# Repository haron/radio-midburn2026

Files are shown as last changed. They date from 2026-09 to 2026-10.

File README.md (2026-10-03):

# Радио

Радио с двумя ручками: одна выбирает город, другая эпоху, переключение идёт
через шум. Станции «в эфире»: вернёшься — песня ушла вперёд.

Модель корпуса: `Radio.stl`. Исходник:
<https://cad.onshape.com/documents/3f97c19d22cdfbb1ff89ef73/w/63b62facf99d46d81c1500a9/e/cb74c49569cd1aa5f598bcb6>

## Города

Лондон, Париж, Берлин, Рим, Краков, Москва, Нью-Йорк, Лос-Анджелес, Токио,
Тель-Авив, Буэнос-Айрес, Гавана, Дели

## Скачать музыку

[Поставь uv](https://docs.astral.sh/uv/getting-started/installation/), затем:

``` sh
uvx --with curl_cffi yt-dlp --cookies-from-browser chrome --js-runtimes node --remote-components ejs:github --no-warnings https://youtu.be/-bWo0ky8xAs
```

`chrome` замени на свой браузер.

## Установка

``` sh
brew install mpd ffmpeg mp3gain uv # Mac
sudo apt install mpd ffmpeg && curl -LsSf https://astral.sh/uv/install.sh | sh # Raspberry Pi
sudo systemctl disable --now mpd mpd.socket # Pi: штатный mpd держит звуковую карту
cp .env.example .env
```

## WiFi

`cp wifi.yaml.example wifi.yaml`, впиши сети, `make provision`. Уже настроенные
на Pi сети остаются, сети с тем же SSID обновляются. `wifi.yaml` не коммитится и
не копируется в `/opt/radio`.

## Музыка

``` text
music/
  01_Paris/
    1_30s/*.mp3
    2_60s/*.mp3
    3_90s/*.mp3
  02_London/
    ...
static.mp3
```

- Порядок — по имени папки, ставь числовые префиксы.
- Ручка эпох идёт по всем эпохам всех городов; где эпохи нет — шум. Папки без
  MP3 игнорируются.
- Из `static.mp3` собирается петля `static.flac`; для нового клипа поправь точки
  обрезки в `Makefile`.
- `make normalize` выравнивает громкость (нужен `mp3gain`).

## Запуск

``` sh
make local
```

- Клавиатура: ←/→ или A/D — город, ↑/↓ или W/S — эпоха, T — случайное блуждание.
  На краях ручки упираются.
- На Pi — энкодеры KY-040: CLK/DT на BCM-пины из `.env`, `+` на 3.3V, GND на
  GND.
- Код и конфиг одни для Mac и Pi, аудиовыход определяется сам.
- mpd живёт после выхода и перезапускается при старте. Остановить:
  `pkill -f radio-mpd.conf`.

## Подсветка шкалы

Адресная лента на ESP32 с WLED, подключена к Pi (или Mac) по USB, без WiFi.

- WLED: Config → Sync Interfaces → Serial baud `115200`; LED Preferences → тип
  `WS281x` (RGB, не RGBW, иначе светодиоды съезжают), длина покрывает
  максимальный индекс из `.env`, ограничитель яркости 500 mA (питание от USB
  Pi), «Turn LEDs on after power up» выкл., boot preset `0`; WiFi Setup → AP
  opens `Never`, чтобы не светить точкой доступа.
- Порт: `ls /dev/cu.*` (Mac) или `ls /dev/serial/by-id/` (Pi) → `WLED_PORT`.
  Путь by-id переживает переподключение.
- Pi нужен блок 5.1V 2.5A: при просадке
  (`cat /sys/class/hwmon/hwmon1/in0_lcrit_alarm` = `1`) ESP32 циклически
  перезагружается и порт пропадает.
- На Pi пользователь должен быть в группе `dialout`:
  `sudo usermod -aG dialout $USER` и перелогиниться. Без порта, прав или ответа
  WLED радио не стартует.

## Охлаждение

Вентилятор 5V, 2 провода (30 или 40 мм) на GPIO Pi: красный на пин 4 (5V),
чёрный на пин 6 (GND), крутится всегда. Ставь на стенку корпуса, чтобы дул на
радиатор, с выходными дырками напротив; вход закрой сеткой от пыли.

`make healthcheck` — температура, троттлинг и просадки, сейчас и с загрузки.

## Шкала

`make radio.pdf` — шкала для печати (60×20 см + 3 мм под обрез) из `scale.py`;
`make radio.png` — превью. Собирать на Mac: нужен Helvetica Neue.

## Настройки (`.env`)

| Ключ | Что это |
|:---|:---|
| `PREVENT_SLEEP` | `1` — не давать машине уснуть |
| `LOG_LEVEL` | `INFO`, или `DEBUG` — ещё и все команды MPD |
| `WALK_IDLE` | секунд бездействия до случайного блуждания: станция 10–20 с, шум 2–7 с, пока не тронут ручку или клавишу |
| `STATIC_FADE` | секунд кроссфейда между музыкой и шумом |
| `STATIC_HOLD` | секунд чистого шума после поворота, \> 0; станция включается через `STATIC_FADE + STATIC_HOLD` |
| `ENC_LOC_A/B`, `ENC_EPOCH_A/B` | пины CLK/DT энкодеров (только Pi) |
| `WLED_PORT` | серийный порт WLED, пусто — без подсветки |
| `LED_LOCATIONS`, `LED_EPOCHS` | первый светодиод каждого диапазона, по одному на город и эпоху, напр. `0,5,10` |
| `LED_LOCATIONS_LEN`, `LED_EPOCHS_LEN` | светодиодов на город / эпоху |
| `LED_ON`, `LED_OFF` | цвета `RRGGBB` выбранной позиции и остальных |

## Логи

- В терминал.
- Syslog по UDP 514 широковещательно в локальную сеть. На сервере скопируй
  `rsyslog-radio.conf` в `/etc/rsyslog.d/` и перезапусти rsyslog; логи в
  `/var/log/radio.log`.
- Лог mpd: `/tmp/radio-mpd.log`.

Решения по дизайну: `AGENTS.md`.

## Песни

`songs.json`: город → эпоха (`1_early`, `2_middle`, `3_modern`) → 3–7 песен.
`make download` докачивает недостающие в `music/` (первый результат поиска
YouTube, нужен ffmpeg) и удаляет те, которых больше нет в списке.

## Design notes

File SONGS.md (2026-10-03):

# Songs

## London

- Early
  - John McCormack — It’s a Long Way to Tipperary (1914)
  - Vera Lynn — We’ll Meet Again (1939)
  - Vera Lynn — The White Cliffs of Dover (1942)
  - Lonnie Donegan — Rock Island Line (1955)
  - Cliff Richard — Move It (1958)
  - Monty Norman — James Bond Theme (1962)
- Middle
  - The Rolling Stones — (I Can’t Get No) Satisfaction (1965)
  - The Kinks — Waterloo Sunset (1967)
  - The Beatles — Hey Jude (1968)
  - David Bowie — Space Oddity (1969)
  - Queen — Bohemian Rhapsody (1975)
  - Sex Pistols — God Save the Queen (1977)
  - The Clash — London Calling (1979)
- Modern
  - Blur — Parklife (1994)
  - Oasis — Wonderwall (1995)
  - The Prodigy — Firestarter (1996)
  - Radiohead — Karma Police (1997)
  - Massive Attack — Teardrop (1998)
  - Arctic Monkeys — I Bet You Look Good on the Dancefloor (2005)
  - Amy Winehouse — Rehab (2006)

## Paris

- Early
  - Lucienne Boyer — Parlez-moi d’amour (1930)
  - Joséphine Baker — J’ai deux amours (1930)
  - Charles Trenet — La Mer (1946)
  - Édith Piaf — La Vie en rose (1947)
  - Yves Montand — Les feuilles mortes (1949)
- Middle
  - Jacques Brel — Ne me quitte pas (1959)
  - Édith Piaf — Non, je ne regrette rien (1960)
  - Charles Aznavour — La Bohème (1965)
  - Francis Lai — Un homme et une femme (1966)
  - Serge Gainsbourg & Jane Birkin — Je t’aime… moi non plus (1969)
  - Joe Dassin — Les Champs-Élysées (1969)
  - Dalida & Alain Delon — Paroles, paroles (1973)
- Modern
  - MC Solaar — Bouge de là (1991)
  - IAM — Je danse le Mia (1993)
  - Daft Punk — Around the World (1997)
  - Air — Sexy Boy (1998)
  - Manu Chao — Me gustas tú (2001)
  - Yann Tiersen — Comptine d’un autre été, l’après-midi (2001)
  - Christine and the Queens — Christine (2014)

## Berlin

- Early
  - Kurt Gerron — Die Moritat von Mackie Messer (1928)
  - Marlene Dietrich — Ich bin von Kopf bis Fuß auf Liebe eingestellt (1930)
  - Comedian Harmonists — Mein kleiner grüner Kaktus (1934)
  - Marlene Dietrich — Lili Marleen (1944)
  - Bully Buhlan — Ich hab noch einen Koffer in Berlin (1951)
- Middle
  - Drafi Deutscher — Marmor, Stein und Eisen bricht (1965)
  - Hildegard Knef — Für mich soll’s rote Rosen regnen (1968)
  - Kraftwerk — Das Model (1978)
  - Klaus Doldinger — Das Boot (1981)
  - Trio — Da Da Da (1982)
  - Nena — 99 Luftballons (1983)
  - Scorpions — Wind of Change (1990)
- Modern
  - Die Ärzte — Schrei nach Liebe (1993)
  - Paul van Dyk — For an Angel (1994)
  - Rammstein — Du hast (1997)
  - Seeed — Dickes B (2001)
  - Wir sind Helden — Guten Tag (2003)
  - Peter Fox — Schwarz zu blau (2008)
  - Paul Kalkbrenner — Sky and Sand (2008)

## Rome

- Early
  - Enrico Caruso — ’O sole mio (1916)
  - Beniamino Gigli — Mamma (1940)
  - Renato Carosone — Tu vuò fà l’americano (1956)
  - Domenico Modugno — Nel blu dipinto di blu (1958)
- Middle
  - Mina — Il cielo in una stanza (1960)
  - Ennio Morricone — Il buono, il brutto, il cattivo (1966)
  - Adriano Celentano — Azzurro (1968)
  - Lucio Battisti — Emozioni (1970)
  - Nino Rota — Speak Softly Love (The Godfather Love Theme) (1972)
  - Toto Cutugno — L’italiano (1983)
  - Lucio Dalla — Caruso (1986)
- Modern
  - 883 — Hanno ucciso l’Uomo Ragno (1992)
  - Jovanotti — L’ombelico del mondo (1995)
  - Eiffel 65 — Blue (Da Ba Dee) (1998)
  - Caparezza — Fuori dal tunnel (2003)
  - Francesco Gabbani — Occidentali’s Karma (2017)
  - Mahmood — Soldi (2019)
  - Måneskin — Zitti e buoni (2021)

## Moscow

- Early
  - Fyodor Chaliapin — Ey, ukhnem (1902)
  - Tamara Tsereteli — Dorogoy dlinnoyu (1925)
  - Leonid Utesov — Bublichki (1930)
  - Lidiya Ruslanova — Katyusha (1938)
  - Alexandrov Ensemble — Svyashchennaya voyna (1941)
  - Mark Bernes — Tyomnaya noch (1943)
  - Иван Шмелёв — Вот солдаты идут (1946)
  - Alexandrov Ensemble — Kalinka (1946)
- Middle
  - Vladimir Troshin — Podmoskovnye vechera (1956)
  - Aida Vedishcheva — Pesenka o medvedyakh (1967)
  - Vladimir Vysotsky — Pesnya o druge (1967)
  - Muslim Magomaev — Luch solntsa zolotogo (1973)
  - Alla Pugacheva — Million alykh roz (1982)
  - Alyans — Na zare (1987)
  - Kino — Gruppa krovi (1988)
- Modern
  - Kino — Kukushka (1990)
  - DDT — Chto takoe osen (1991)
  - Agata Kristi — Kak na voyne (1993)
  - Mumiy Troll — Utekay (1997)
  - Bi-2 — Polkovniku nikto ne pishet (2000)
  - Zemfira — Iskala (2000)
  - Splean — Vykhoda net (2001)

## New York

- Early
  - Benny Goodman — Sing, Sing, Sing (1937)
  - The Andrews Sisters — Bei Mir Bist Du Schön (1937)
  - Louis Armstrong — When the Saints Go Marching In (1938)
  - Billie Holiday — Strange Fruit (1939)
  - Glenn Miller — In the Mood (1939)
  - Duke Ellington — Take the ‘A’ Train (1941)
- Middle
  - Louis Armstrong — Go Down Moses (Let My People Go) (1958)
  - Ray Charles — Hit the Road Jack (1961)
  - Frank Sinatra — Fly Me to the Moon (1964)
  - Aretha Franklin — Respect (1967)
  - Ramones — Blitzkrieg Bop (1976)
  - Blondie — Heart of Glass (1979)
  - Grandmaster Flash and the Furious Five — The Message (1982)
- Modern
  - Run-DMC & Aerosmith — Walk This Way (1986)
  - Beastie Boys — (You Gotta) Fight for Your Right (To Party!) (1986)
  - Madonna — Vogue (1990)
  - Fugees — Killing Me Softly (1996)
  - The Strokes — Last Nite (2001)
  - 50 Cent — In da Club (2003)
  - Jay-Z & Alicia Keys — Empire State of Mind (2009)

## Los Angeles

- Early
  - Judy Garland — Over the Rainbow (1939)
  - Bing Crosby — White Christmas (1942)
  - Woody Guthrie — This Land Is Your Land (1944)
  - Hank Williams — Your Cheatin’ Heart (1953)
  - Bill Haley & His Comets — Rock Around the Clock (1954)
- Middle
  - Elvis Presley — Hound Dog (1956)
  - Chuck Berry — Johnny B. Goode (1958)
  - Henry Mancini — The Pink Panther Theme (1963)
  - The Beach Boys — Good Vibrations (1966)
  - The Doors — Light My Fire (1967)
  - The Doors — People Are Strange (1967)
  - Eagles — Hotel California (1976)
  - Michael Jackson — Billie Jean (1983)
- Modern
  - Nirvana — Smells Like Teen Spirit (1991)
  - Rage Against the Machine — Killing in the Name (1992)
  - Dr. Dre — Nuthin’ but a ‘G’ Thang (1992)
  - 2Pac — California Love (1995)
  - Red Hot Chili Peppers — Californication (1999)
  - Linkin Park — In the End (2001)
  - Kendrick Lamar — HUMBLE. (2017)

## Tokyo

- Early
  - Koto — Sakura Sakura (1950)
  - Hibari Misora — Ringo Oiwake (1952)
  - Akira Ifukube — Godzilla Main Theme (1954)
  - Kyu Sakamoto — Ue o Muite Aruko (1961)
- Middle
  - Sayuri Ishikawa — Tsugaru Kaikyo Fuyugeshiki (1977)
  - Yellow Magic Orchestra — Rydeen (1980)
  - Ryuichi Sakamoto — Merry Christmas Mr. Lawrence (1983)
  - Saburo Kitajima — Matsuri (1984)
  - Mariya Takeuchi — Plastic Love (1984)
  - Azumi Inoue — Tonari no Totoro (1988)
  - Hibari Misora — Kawa no Nagare no Yo ni (1989)
- Modern
  - Yoko Takahashi — Zankoku na Tenshi no Teze (1995)
  - Youmi Kimura — Itsumo Nando Demo (2001)
  - Yoshida Brothers — Rising (2003)
  - Perfume — Polyrhythm (2007)
  - Kyary Pamyu Pamyu — PonPonPon (2011)
  - Babymetal — Gimme Chocolate!! (2014)
  - Kenshi Yonezu — Lemon (2018)

## Tel Aviv

- Early
  - Yaffa Yarkoni — Hayu Leilot (1948)
  - Shoshana Damari — Kalaniyot (1951)
  - HaDudaim — Erev Shel Shoshanim (1957)
  - Ran & Nama — Hava Nagila (1959)
- Middle
  - Shuli Natan — Yerushalayim Shel Zahav (1967)
  - Lehakat HaNahal — Shir LaShalom (1969)
  - Arik Einstein — Ani ve’Ata (1971)
  - Kaveret — Yo Ya (1974)
  - Gali Atari & Milk and Honey — Hallelujah (1979)
  - Zohar Argov — HaPerach BeGani (1982)
  - Ofra Haza — Im Nin’alu (1984)
- Modern
  - Aviv Geffen — Achshav Meunan (1993)
  - Berry Sakharof — Bo (1996)
  - Hadag Nahash — Shirat HaSticker (2004)
  - Idan Raichel Project — Mima’amakim (2005)
  - Infected Mushroom — Becoming Insane (2007)
  - Omer Adam — Tel Aviv (2014)
  - Netta — Toy (2018)

## Buenos Aires

- Early
  - Carlos Gardel — Por una cabeza (1935)
  - Carlos Gardel — Volver (1935)
  - Atahualpa Yupanqui — Los ejes de mi carreta (1944)
  - Aníbal Troilo — Sur (1948)
  - Juan D’Arienzo — La Cumparsita (1951)
- Middle
  - Astor Piazzolla — Adiós Nonino (1959)
  - Los Gatos — La balsa (1967)
  - Mercedes Sosa — Alfonsina y el mar (1969)
  - Sui Generis — Canción para mi muerte (1972)
  - Astor Piazzolla — Libertango (1974)
  - Soda Stereo — Persiana americana (1986)
- Modern
  - Soda Stereo — De música ligera (1990)
  - Los Fabulosos Cadillacs — Matador (1993)
  - Bersuit Vergarabat — Se viene (2000)
  - Gotan Project — Santa María (del Buen Ayre) (2001)
  - Bajofondo — Pa’ bailar (2007)
  - Bizarrap & Nathy Peluso — Bzrp Music Sessions, Vol. 36 (2020)

## Havana

- Early
  - Don Azpiazu — El manisero (1930)
  - Joseíto Fernández — Guantanamera (1940)
  - Pérez Prado — Mambo No. 5 (1949)
  - Celia Cruz & La Sonora Matancera — Burundanga (1953)
  - Benny Moré — Bonito y sabroso (1953)
  - Orquesta Aragón — El bodeguero (1955)
- Middle
  - Carlos Puebla — Hasta siempre, Comandante (1965)
  - Pablo Milanés — Yolanda (1970)
  - Silvio Rodríguez — Ojalá (1978)
  - Los Van Van — Sandunguera (1982)
- Modern
  - Buena Vista Social Club — Chan Chan (1997)
  - Ibrahim Ferrer — Dos gardenias (1997)
  - Orishas — 537 C.U.B.A. (2000)
  - Gente de Zona & Marc Anthony — La Gozadera (2015)
  - Cimafunk — Me voy (2017)

## Delhi

- Early
  - K.L. Saigal — Jab Dil Hi Toot Gaya (1946)
  - Lata Mangeshkar — Aayega Aanewala (1949)
  - Geeta Dutt — Babuji Dheere Chalna (1954)
  - Mukesh — Mera Joota Hai Japani (1955)
  - Mohammed Rafi — Chaudhvin Ka Chand (1960)
  - Lata Mangeshkar — Pyar Kiya To Darna Kya (1960)
- Middle
  - Lata Mangeshkar — Ae Mere Watan Ke Logon (1963)
  - Kishore Kumar — Mere Sapno Ki Rani (1969)
  - Asha Bhosle — Dum Maro Dum (1971)
  - Kishore Kumar & Manna Dey — Yeh Dosti (1975)
  - R.D. Burman — Mehbooba Mehbooba (1975)
  - Vijay Benedict — I Am a Disco Dancer (1982)
- Modern
  - Sukhwinder Singh & Sapna Awasthi — Chaiyya Chaiyya (1998)
  - Daler Mehndi — Tunak Tunak Tun (1998)
  - Panjabi MC — Mundian To Bach Ke (1998)
  - A.R. Rahman — Jai Ho (2008)
  - Mohit Chauhan — Masakali (2009)
  - Aditi Paul & Osman Mir — Nagada Sang Dhol (2013)
  - Rahul Sipligunj & Kaala Bhairava — Naatu Naatu (2022)

## Kraków

- Early
  - Hanka Ordonówna — Miłość ci wszystko wybaczy (1933)
  - Mieczysław Fogg — Ostatnia niedziela (1936)
  - Molly Picon — Yidl Mitn Fidl (1936)
  - Eugeniusz Bodo — Umówiłem się z nią na dziewiątą (1937)
- Middle
  - Ewa Demarczyk — Karuzela z madonnami (1962)
  - Czesław Niemen — Dziwny jest ten świat (1967)
  - Krzysztof Komeda — Rosemary’s Baby (Lullaby) (1968)
  - Marek Grechuta & Anawa — Niepewność (1969)
  - Perfect — Autobiografia (1981)
  - Lady Pank — Mniej niż zero (1983)
  - Maanam — Kocham cię, kochanie moje (1984)
- Modern
  - Hey — Teksański (1993)
  - Kazik — 12 groszy (1997)
  - Myslovitz — Długość dźwięku samotności (1999)
  - Paktofonika — Jestem Bogiem (2000)
  - Brodka — Granda (2010)
  - Taco Hemingway — Deszcz na betonie (2016)
  - Dawid Podsiadło — Małomiasteczkowy (2018)

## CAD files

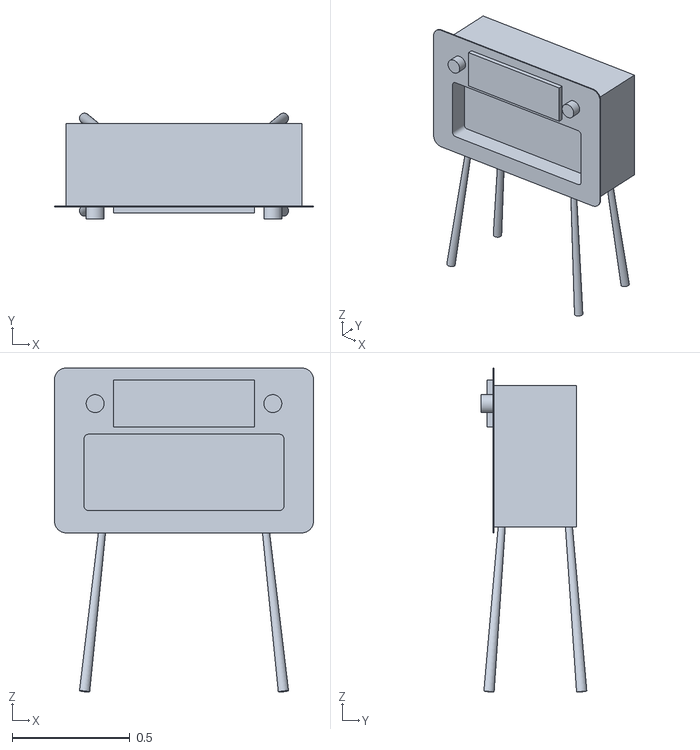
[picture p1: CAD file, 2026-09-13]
Radio.stl
1.10 x 0.449 x 1.38

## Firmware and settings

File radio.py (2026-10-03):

"""Two-knob radio: location × epoch stations, switched through static. Design notes in AGENTS.md."""
import atexit
import grp
import json
import logging
import logging.handlers
import os
import random
import re
import socket
import subprocess
import sys
import termios
import threading
import time
import tty
import zlib
from dataclasses import dataclass
from pathlib import Path

import psutil
import serial
from dotenv import load_dotenv
from mpd import MPDClient
from mutagen.mp3 import MP3

ROOT = Path(__file__).resolve().parent
MUSIC, STATIC = ROOT / "music", ROOT / "static.flac"  # seamless loop built by `make static.flac`
SOCK, CONF = "/tmp/radio-mpd.sock", Path("/tmp/radio-mpd.conf")
TICK = 0.02
WALK_PLAY, WALK_STATIC = (10, 20), (2, 7)  # random walk: seconds on a station, then of static
FLICKER, FLICKER_MIN = 0.06, 0.15  # selected LEDs during static: seconds per frame, lowest brightness
PI_MODEL = Path("/proc/device-tree/model")
ON_PI = PI_MODEL.exists() and "Raspberry Pi" in PI_MODEL.read_text()
KEYS = {"\x1b[D": ("location", -1), "a": ("location", -1), "\x1b[C": ("location", 1), "d": ("location", 1),
        "\x1b[A": ("epoch", 1), "w": ("epoch", 1), "\x1b[B": ("epoch", -1), "s": ("epoch", -1)}

log = logging.getLogger("radio")


class BroadcastSyslog(logging.handlers.SysLogHandler):
    """Syslog to each interface's broadcast address (macOS rejects 255.255.255.255); re-read per record."""

    def __init__(self):
        super().__init__(("255.255.255.255", 514))
        self.socket.setsockopt(socket.SOL_SOCKET, socket.SO_BROADCAST, 1)
        self.ident = "radio: "

    def emit(self, record):
        for addrs in psutil.net_if_addrs().values():
            for a in addrs:
                if a.family == socket.AF_INET and a.broadcast:
                    self.address = (a.broadcast, 514)
                    super().emit(record)

    def handleError(self, record):
        pass  # no network (offline at the event) must not break playback


@dataclass
class Station:
    name: str
    tracks: list[tuple[Path, float]]

    def live(self) -> tuple[int, float]:
        """(track index, offset) that is 'on air' right now; stations run on the wall clock."""
        total = sum(d for _, d in self.tracks)
        pos = (time.time() + zlib.crc32(self.name.encode()) % total) % total
        for i, (_, d) in enumerate(self.tracks):
            if pos < d or i == len(self.tracks) - 1:
                return i, min(pos, d)
            pos -= d


def scan() -> tuple[list[str], list[str], list[list[Station | None]]]:
    """Locations, epochs (union over all locations) and lib[loc][epoch]; None where a location lacks the epoch.
    Only folders with mp3 files count."""
    if not STATIC.is_file():
        sys.exit(f"missing {STATIC}, run `make static.flac`")
    dirs = {d: sorted(d.glob("*.mp3")) for d in MUSIC.glob("*/*") if d.is_dir()}
    dirs = {d: ts for d, ts in dirs.items() if ts}
    if not dirs:
        sys.exit(f"no mp3 files in {MUSIC}/<location>/<epoch>/")
    locs, epochs = (sorted({d.parts[i] for d in dirs}) for i in (-2, -1))
    lib = [[Station(f"{loc}/{ep}", [(t, MP3(t).info.length) for t in dirs[d]]) if (d := MUSIC / loc / ep) in dirs
            else None for ep in epochs] for loc in locs]
    return locs, epochs, lib


def output_type() -> str:
    if sys.platform == "darwin":
        return "osx"
    return "pipewire" if Path(os.environ.get("XDG_RUNTIME_DIR", "/nonexistent"), "pipewire-0").exists() else "alsa"


def mpd_up() -> bool:
    with socket.socket(socket.AF_UNIX) as s:  # a stale socket file stays behind after mpd dies
        return s.connect_ex(SOCK) == 0


def start_mpd(out: str):
    buf = '\tbuffer_time "100000"\n' if out == "alsa" else ""  # MPD's 500ms default delays every volume change
    outputs = "".join(f'audio_output {{\n\ttype "{out}"\n\tname "{n}"\n\tmixer_type "software"\n{buf}}}\n'
                      for n in ("music", "static"))
    CONF.write_text(f'bind_to_address "{SOCK}"\nlog_file "/tmp/radio-mpd.log"\n'
                    f'connection_timeout "31536000"\n{outputs}')  # our clients may sit idle for hours
    # an old mpd may hold a dead audio device (macOS: output switched or slept), so always start a fresh one
    old = [p for p in psutil.process_iter(["cmdline"]) if str(CONF) in (p.info["cmdline"] or [])]
    for p in old:
        p.terminate()
    if psutil.wait_procs(old, timeout=5)[1]:
        sys.exit(f"old mpd didn't exit: {[p.pid for p in old]}")
    if old:
        log.info("stopped old mpd %s", [p.pid for p in old])
    subprocess.run(["mpd", str(CONF)], check=True, start_new_session=True)  # survive our Ctrl+C
    for _ in range(50):  # the daemon returns before its socket is bound
        if mpd_up():
            break
        time.sleep(0.1)
    else:
        sys.exit(f"mpd didn't create {SOCK}, see /tmp/radio-mpd.log")
    log.info("mpd started with %s", CONF)


def keep_awake():
    pid = str(os.getpid())
    cmd = (["caffeinate", "-ims", "-w", pid] if sys.platform == "darwin" else
           ["systemd-inhibit", "--what=idle:sleep", "--who=radio", "--why=playing", "tail", f"--pid={pid}", "-f", "/dev/null"])
    proc = subprocess.Popen(cmd)
    time.sleep(0.3)
    if proc.poll() is not None:
        sys.exit(f"keep-awake failed: {' '.join(cmd)} exited with {proc.returncode}")
    log.info("keep-awake on: %s", " ".join(cmd))


def connect(partition: str | None = None) -> MPDClient:
    client = MPDClient()
    client.connect(SOCK)
    if partition:
        if partition not in {p["partition"] for p in client.listpartitions()}:
            client.newpartition(partition)
        client.partition(partition)
    client.moveoutput(partition or "music")
    return client


class Leds:
    """WLED on USB serial, JSON API. WLED keeps the state, so a frame is sent only when the selection changes."""

    def __init__(self, port: str, locations: int, epochs: int):
        self.locs, self.epochs = led_ranges("LED_LOCATIONS"), led_ranges("LED_EPOCHS")
        if (len(self.locs), len(self.epochs)) != (locations, epochs):
            sys.exit(f"LED_LOCATIONS has {len(self.locs)} ranges for {locations} locations, "
                     f"LED_EPOCHS has {len(self.epochs)} for {epochs} epochs")
        self.spans = []  # adjacent ranges merged: native-USB WLED (ESP32-C3/S3) drops JSON over its 256-byte RX buffer
        for a, b in sorted(self.locs + self.epochs):
            if self.spans and self.spans[-1][1] == a:
                self.spans[-1] = (self.spans[-1][0], b)
            else:
                self.spans.append((a, b))
        self.on, self.off = (os.environ[k] for k in ("LED_ON", "LED_OFF"))
        if not all(re.fullmatch(r"[0-9A-Fa-f]{6}", c) for c in (self.on, self.off)):
            sys.exit(f"LED_ON/LED_OFF must be RRGGBB hex, got {self.on}/{self.off}")
        if not Path(port).exists():
            sys.exit(f"WLED not found at {port}")
        if not os.access(port, os.R_OK | os.W_OK):  # checks this process's groups: a fresh usermod needs a re-login
            group = grp.getgrgid(os.stat(port).st_gid).gr_name
            sys.exit(f"no read/write access to {port}: run `sudo usermod -aG {group} $USER` and log in again")
        self.ser = serial.Serial(baudrate=115200, timeout=1, write_timeout=1)
        self.ser.port, self.ser.dtr, self.ser.rts = port, False, False  # set before open, or the ESP32 auto-resets
        self.ser.open()
        for _ in range(5):  # retries cover a board that rebooted on open anyway
            self.ser.reset_input_buffer()
            self.ser.write(b'{"v":true}\n')
            if b'"on":' in self.ser.read_until(b'"on":'):
                break
        else:
            sys.exit(f"no WLED reply on {port}: check Config > Sync Interfaces > Serial baud 115200")
        log.info("leds on: WLED at %s, locations %s, epochs %s", port, self.locs, self.epochs)

    def show(self, loc: int, epoch: int, flicker: bool):
        (la, lb), (ea, eb) = self.locs[loc], self.epochs[epoch]
        on = self.on
        if flicker:
            k = random.uniform(FLICKER_MIN, 1)
            on = "".join(f"{round(int(on[i:i + 2], 16) * k):02X}" for i in (0, 2, 4))
        dim = [x for a, b in self.spans for x in (a, b, self.off)]
        seg = {"id": 0, "fx": 0, "i": dim + [la, lb, on, ea, eb, on]}
        self.ser.write(json.dumps({"on": True, "seg": [seg]}).encode() + b"\n")


def led_ranges(key: str) -> list[tuple[int, int]]:
    """KEY='0,6', KEY_LEN='6' -> [(0, 6), (6, 12)], end-exclusive like WLED's "i"."""
    n = int(os.environ[f"{key}_LEN"])
    return [(a, a + n) for a in map(int, os.environ[key].split(","))]


class Radio:
    def __init__(self, locs: list[str], epochs: list[str], lib: list[list[Station | None]], leds: Leds | None):
        self.locs, self.epochs, self.lib, self.leds = locs, epochs, lib, leds
        self.loc, self.epoch = self.random_station(None)  # every start tunes in somewhere new
        self.fade, self.hold = float(os.environ["STATIC_FADE"]), float(os.environ["STATIC_HOLD"])
        if not (self.fade > 0 and self.hold > 0):  # hold > 0 keeps the station load inside the silence
            sys.exit(f"STATIC_FADE and STATIC_HOLD must be > 0, got {self.fade}/{self.hold}")
        self.walk_idle = float(os.environ["WALK_IDLE"])
        now = time.monotonic()
        self.tune_until = now + self.fade + self.hold  # power-on tunes in through static
        # power-on starts the random walk: the first station plays as a walk step, then hops on
        self.last_activity, self.walking, self.walk_next = now, True, self.tune_until + random.uniform(*WALK_PLAY)
        self.lock = threading.Lock()
        self.music, self.static = connect(), connect("static")
        for c in (self.music, self.static):
            c.stop()
            c.clear()
            c.setvol(0)
        self.music.repeat(1), self.music.single(0), self.music.consume(0), self.music.crossfade(0)
        self.static.add(f"file://{STATIC}"), self.static.repeat(1), self.static.single(1)
        self.static.play()  # never paused: resuming reopens the ALSA device, which delays the static
        self.vol = {"music": 0.0, "static": 0.0}
        log.info("random walk on -> %s", self.name())

    def activity(self):
        """Any knob or key: back to normal mode."""
        with self.lock:
            self.last_activity = time.monotonic()
            if self.walking:
                self.walking = False
                log.info("random walk off")

    def start_walk(self):
        with self.lock:
            if not self.walking:
                self.walking, self.walk_next = True, time.monotonic()
                log.info("random walk on")

    def random_station(self, exclude: tuple[int, int] | None) -> tuple[int, int]:
        return random.choice([(li, ei) for li, row in enumerate(self.lib) for ei, st in enumerate(row)
                              if st and (li, ei) != exclude])

    def walk_step(self, now: float):
        """Under the lock: jump to a random other station, through WALK_STATIC seconds of static."""
        self.loc, self.epoch = self.random_station((self.loc, self.epoch))
        self.tune_until = now + self.fade + random.uniform(*WALK_STATIC)
        self.walk_next = self.tune_until + random.uniform(*WALK_PLAY)
        log.info("random walk -> %s", self.name())

    def turn(self, knob: str, delta: int):
        self.activity()
        with self.lock:
            attr, count = ("loc", len(self.locs)) if knob == "location" else ("epoch", len(self.epochs))
            new = getattr(self, attr) + delta
            if not 0 <= new < count:  # no wrapping: turning past an end does nothing, not even static
                log.info("%s %+d ignored, already at %s", knob, delta, self.name())
                return
            setattr(self, attr, new)
            self.tune_until = time.monotonic() + self.fade + self.hold
            name = self.name()
        log.info("%s %+d -> %s%s", knob, delta, name, "" if self.lib[self.loc][self.epoch] else " (no station)")

    def name(self) -> str:
        return f"{self.locs[self.loc]}/{self.epochs[self.epoch]}"

    def load(self, st: Station):
        i, offset = st.live()
        self.music.clear()
        for path, _ in st.tracks:
            self.music.add(f"file://{path}")
        self.music.seek(i, f"{offset:.3f}")
        log.info("tuned %s: track %d/%d %r @ %d:%02d", st.name, i + 1, len(st.tracks), st.tracks[i][0].name,
                 offset // 60, offset % 60)

    def ramp(self, name: str, client: MPDClient, target: int):
        v = self.vol[name]
        nv = min(target, v + 100 * TICK / self.fade) if target > v else max(target, v - 100 * TICK / self.fade)
        if nv == v:
            return
        client.setvol(round(nv))
        self.vol[name] = nv

    def run(self):
        loaded, phase, lit, flick_at = None, None, None, 0.0
        while True:
            now = time.monotonic()
            if not self.walking and now > self.last_activity + self.walk_idle:
                self.start_walk()
            with self.lock:
                if self.walking and now >= self.walk_next:
                    self.walk_step(now)
                st, tune_until, pos = self.lib[self.loc][self.epoch], self.tune_until, (self.loc, self.epoch)
            # no station at this location and epoch: static only
            tuning = st is None or now < tune_until
            # the scale follows the knob right away, not after the static, and flickers while it lasts
            if self.leds and ((pos, tuning) != lit or tuning and now >= flick_at):
                self.leds.show(*pos, tuning)
                lit, flick_at = (pos, tuning), now + FLICKER
            if not tuning and st is not loaded:  # music is silent by now: fade < fade + hold
                self.load(st)
                loaded = st
            self.ramp("music", self.music, 0 if tuning else 100)
            self.ramp("static", self.static, 100 if tuning else 0)
            m = self.vol["music"]
            new_phase = ("fading out" if m else "static") if tuning else (f"playing {st.name}" if m == 100 else "fading in")
            if new_phase != phase:
                log.info(new_phase)
                phase = new_phase
            time.sleep(TICK)

    def stop(self):
        self.music.stop()
        self.static.stop()


def keyboard(radio: Radio):
    fd = sys.stdin.fileno()
    atexit.register(termios.tcsetattr, fd, termios.TCSADRAIN, termios.tcgetattr(fd))
    tty.setcbreak(fd)

    def read():
        while True:
            for key in re.findall(r"\x1b\[[A-D]|[^\x1b]", os.read(fd, 64).decode(errors="ignore")):
                if (k := key if len(key) > 1 else key.lower()) == "t":
                    radio.start_walk()
                elif k in KEYS:
                    radio.turn(*KEYS[k])
                else:
                    radio.activity()

    threading.Thread(target=read, daemon=True).start()
    log.info("keyboard on: <-/-> or A/D location, up/down or W/S epoch, T random walk")


def encoders(radio: Radio) -> list:
    from gpiozero import RotaryEncoder

    encs = []
    for knob, env in (("location", "ENC_LOC"), ("epoch", "ENC_EPOCH")):
        enc = RotaryEncoder(int(os.environ[f"{env}_A"]), int(os.environ[f"{env}_B"]))
        enc.when_rotated_clockwise = lambda k=knob: radio.turn(k, 1)
        enc.when_rotated_counter_clockwise = lambda k=knob: radio.turn(k, -1)
        encs.append(enc)
    log.info("encoders on: location %s/%s, epoch %s/%s", os.environ["ENC_LOC_A"], os.environ["ENC_LOC_B"],
             os.environ["ENC_EPOCH_A"], os.environ["ENC_EPOCH_B"])
    return encs


def main():
    load_dotenv(ROOT / ".env")
    console = logging.StreamHandler()
    console.setFormatter(logging.Formatter("%(asctime)s %(levelname)s %(name)s: %(message)s"))
    syslog = BroadcastSyslog()
    syslog.setFormatter(logging.Formatter("%(levelname)s %(name)s: %(message)s"))
    logging.basicConfig(level=os.environ["LOG_LEVEL"], handlers=[console, syslog])

    locs, epochs, lib = scan()
    for loc, stations in zip(locs, lib):
        log.info("library %s: %s", loc, ", ".join(f"{ep} ({len(st.tracks) if st else 0} tracks)"
                                                   for ep, st in zip(epochs, stations)))
    out = output_type()
    log.info("platform %s, raspberry pi: %s, mpd output: %s", sys.platform, ON_PI, out)
    if os.environ["PREVENT_SLEEP"] == "1":
        keep_awake()
    else:
        log.info("keep-awake off")
    if port := os.environ["WLED_PORT"]:
        leds = Leds(port, len(locs), len(epochs))
    else:
        leds = None
        log.info("leds off: WLED_PORT is empty")
    start_mpd(out)

    radio = Radio(locs, epochs, lib, leds)
    if sys.stdin.isatty():
        keyboard(radio)
    encs = encoders(radio) if ON_PI else []  # noqa: F841 keep references alive
    try:
        radio.run()
    except KeyboardInterrupt:
        log.info("stopping")
        radio.stop()


if __name__ == "__main__":
    main()

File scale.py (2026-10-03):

"""Dial scale as SVG on stdout: epoch bands on the left, cities on the main line, both in knob (folder) order."""
import re
import unicodedata
from xml.sax.saxutils import escape

from radio import scan

W, H, LINE = 1800, 600, 300
X0, X1 = 520, 1700  # first and last city tick; even steps, so each tick sits over its LEDs
SEP = 400  # right edge of the band frame
FONT = 'font-family="Helvetica Neue" font-weight="bold" font-size="38"'
TICK, MAIN, FRAME = 3, 18, 6  # stroke widths
OVERRUN = 25  # main line past the end ticks
EPOCHS = {"1_early": "Gramophone", "2_middle": "Vinyl", "3_modern": "Digital"}  # scale names for epoch folders


def label(name: str) -> str:
    name = unicodedata.normalize("NFKD", re.sub(r"^\d+_", "", name)).encode("ascii", "ignore").decode()  # Kraków -> Krakow
    return escape(" ".join(w[:1].upper() + w[1:] for w in name.split()))


def svg(locs: list[str], epochs: list[str]) -> str:
    step = (X1 - X0) / (len(locs) - 1)
    out = [f'<svg xmlns="http://www.w3.org/2000/svg" viewBox="0 0 {W} {H}" width="{W}" height="{H}">',
           f'<rect width="{W}" height="{H}" fill="#000"/>', '<g stroke="#fff" fill="none">',
           f'<line x1="{X0 - OVERRUN}" y1="{LINE}" x2="{X1 + OVERRUN}" y2="{LINE}" stroke-width="{MAIN}"/>',
           f'<rect x="24" y="{LINE - 190}" width="{SEP - 24}" height="380" stroke-width="{FRAME}"/>']
    for i in range(len(locs)):
        x, dy = X0 + step * i, -80 if i % 2 == 0 else 80
        out.append(f'<line x1="{x:.1f}" y1="{LINE}" x2="{x:.1f}" y2="{LINE + dy}" stroke-width="{TICK}"/>')
    bands = [LINE + 120 * (i - (len(epochs) - 1) / 2) for i in range(len(epochs))]
    out += [f'<circle cx="74" cy="{y:.1f}" r="15" fill="#fff" stroke="none"/>' for y in bands]
    out.append(f'</g><g fill="#fff" {FONT}>')
    for i, loc in enumerate(locs):
        x = X0 + step * i
        name, top = label(loc), i % 2 == 0
        lines = name.split(" ", 1) if len(name) > 10 else [name]  # long names in two lines, growing away from the line
        y = LINE - 100 - 40 * (len(lines) - 1) if top else LINE + 140
        spans = "".join(f'<tspan x="{x:.1f}" dy="{40 * (j > 0)}">{t}</tspan>' for j, t in enumerate(lines))
        out.append(f'<text x="{x:.1f}" y="{y}" text-anchor="middle">{spans}</text>')
    out += [f'<text x="104" y="{y + 15:.1f}">{label(EPOCHS[ep])}</text>' for ep, y in zip(epochs, bands)]
    out.append("</g></svg>")
    return "\n".join(out)


if __name__ == "__main__":
    locs, epochs, _ = scan()
    print(svg(locs, epochs))

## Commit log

2026-09-24 fix: reduce ALSA latency and keep static playback ready for transitions
    [radio.py]
2026-10-03 feat: flicker selected LEDs during static and support compact WLED ranges
2026-10-03 feat: Generate radio preview from cut-ready text curves
2026-10-03 feat: add print-ready radio PDF output and simplify scale graphics
2026-10-03 fix: Prevent Raspberry Pi sleep and recover from kernel hangs
2026-10-03 feat: Start the random walk on power-up and update timing documentation
2026-10-03 Add Raspberry Pi health checks and configure thermal monitoring
2026-10-11 Add configurable print reserve margins to the radio PDF build
2026-10-23 Add LED range for the new location and document NFC folder naming requirements
2026-10-23 Add configurable radio volume and encoder detent filtering
